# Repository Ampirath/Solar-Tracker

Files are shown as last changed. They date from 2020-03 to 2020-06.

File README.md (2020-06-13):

# Solar-Tracker

ΕΠΑΛ ΚΙΣΑΜΟΥ-ΓΕΛ ΚΙΣΑΜΟΥ

Η ηλιακή ενέργεια αποτελεί ανανεώσιμη πηγή ενέργειας με πρόσφορη μέθοδο χρησιμοποίησή της τα φωτοβολταϊκά πάνελ. Όμως ο ήλιος αποδίδει τα μέγιστα μόνο όταν «πέφτει» κάθετα στο πάνελ, έτσι ψάχνουμε τρόπο να ακολουθεί το πάνελ τις ακτίνες του ήλιου. Ένας τρόπος παρακολούθησης του είναι με φωτοευαίσθητες αντιστάσεις οι οποίες παρακολουθούνται από τον μικροελεγκτή arduino και με servo ο μικροελεγκτής προσαρμόζει το πάνελ ώστε οι ακτίνες να πέφτουν κάθετα. 

Υλικά :

1.arduino uno 
2. 4 ldr 
3. 2 servo (link: https://grobotronics.com/servo-small-5kg.cm-metal-gears-with-analog-feedback-feetech-fs9225m.html                                       https://grobotronics.com/analog-feedback-micro-servo-plastic-gear.html ) 
4.wires 
5.breadboard (link: https://grobotronics.com/adafruit-perma-proto-quarter-sized-breadboard-pcb-single.html ) 
6.Πλαστικά γρανάζια απο 3D εκτυπωτή του εκφέ χανίων (ΤΑ STL ΑΡΧΕΙΑ ΠΕΡΙΛΑΜΒΑΝΟΝΤΑΙ ΩΣ STL-files )

ΤΕΛΙΚΗ ΠΕΡΙΓΡΑΦΗ ΠΡΟΒΛΗΜΑΤΟΣ

Η εποχή μας απαιτεί μεγάλα ενεργειακά αποθέματα , έτσι ένα αποδοτικό φωτοβολταικό πάνελ που ακολουθεί τον ήλιο μας δείχνει τον δρόμο στους κατασκευαστές φωτοβ.συστημάτων. Πόσο μάλλον όταν το πρότζεκτ μας καταγράφει online τις γωνίες που δημιουργεί ο ήλιος στην περιοχή όπου χρησιμοποιείται και έτσι δείχνει ανα ημέρα και ώρα την κατάλληλη γωνία που πρέπει να έχει το φ. πάνελ για μέγιστη απόδοση. 
Το μοίρασμα της γνώσης προτεραιότητα μας! Μια επιστημονική εργασία αυτού του είδους εκπαιδεύει τους μελλοντικούς μας επιστήμονες στο διαθεματικό πλαίσιο STEM-ΘΕΤΙΚΕΣ ΕΠΙΣΤΗΜΕΣ-ΡΟΜΠΟΤΙΚΗ - ΑΚΟΛΟΥΘΩΝΤΑΣ ΤΟ ΜΟΝΟΠΑΤΙ ΤΟΥ ΗΛΙΟΥ.
Σε συνέχεια της προηγούμενης απάντησης η ιδέα μας ήταν να κατασκευάσουμε ένα ηλιακό ανιχνευτή της πορείας του ήλιου που θα προσαρμόζει το φωτοβολταικό πάνελ μας κάθετα στις ακτίνες του ήλιου για να έχει την μέγιστη απόδοση και ταυτόχρονα θα καταγράφει τις γωνίες αυτές.
Χρησιμοποιήσαμε 4 ldr φωτοαντιστάσεις -οι αισθητήρες φωτός που ανάλογα με το φως που λαμβάνουν θα δίνουν εντολή να στραφεί το πάνελ μας στη σωστή θέση- 2 σερβομηχανισμούς για να εκτελούν τις παραπάνω εντολές και θα αποτελούν συνάμα αισθητήρες κλίσης για την καταγραφή αυτών των γωνιών. Φυσικά και ένα arduino που είναι ο εγκέφαλος της κατασκευής μας. Τα 3D εκτυπωμένα εξαρτήματα δίνουν σταθερότητα και αποδοτικότητα στην κατασκευή μας. 
Η ομάδα μας αποτελείται απο 3 μαθητές του ΓΕΛ Κισάμου β λυκείου με θαυμαστή όρεξη για μάθηση: 
ΑΘΗΝΑ ΑΘΑΝΑΣΑΚΗ, ΣΤΕΛΑ ΑΜΠΟΥΧΑΝΗ, ΣΠΥΡΟΣ ΕΙΡΗΝΑΚΗΣ 
Τα κορίτσια είναι οι προγραμματίστριες του arduino και ο Σπύρος το πρακτικό μυαλό. (Βέβαια οι απαιτήσεις του έργου ήταν να αναμιχθούν όλοι σε όλα τα στάδια της κατασκευής). Ο Σπύρος βοήθησε και στο 3D σχεδιασμό εξαρτημάτων. 

ΒΙΒΛΙΟΓΡΑΦΙΚΕΣ ΑΝΑΦΟΡΕΣ

1)https://en.wikipedia.org/wiki/Sun_path 
2)https://en.wikipedia.org/wiki/Position_of_the_Sun 
3)https://www.youtube.com/watch?v=lJVEubm9Ja8 
4)https://www.instructables.com/id/Arduino-Solar-Tracker/

LINK ΠΟΥ ΒΟΗΘΗΣΕ ΣΤΗΝ ΒΑΘΜΟΝΟΜΗΣΗ-CALIBRATION SERVO : https://dronebotworkshop.com/analog-feedback-servo-motor/

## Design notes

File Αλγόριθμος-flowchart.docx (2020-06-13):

ΕΑΝ ΠΑΝΩ>ΚΑΤΩ

VERT.SERVO ΠΑΝΩ-ΒΟΡΕΙΑ

ΑΛΛΙΩΣ ΕΑΝ ΚΑΤΩ >ΠΑΝΩ

VERT.SERVO ΚΑΤΩ-ΝΟΤΙΑ

VERT,SERVO ΚΑΤΩ

ΕΑΝ ΟΙ ΔΕΞΙΟΙ-ΑΡΙΣΤΕΡΟΙ ΑΙΣΘΗΤΗΡΕΣ ΕΧΟΥΝ ΜΕΓΑΛΥΤΕΡΗ ΔΙΑΦΟΡΑ ΑΠΟ ΤΗΝ ΕΠΙΤΡΕΠΟΜΕΝΗ

↓

ΚΑΤΕΓΡΑΨΕ ΓΩΝΙΕΣ

1) γωνία ύψους-altitude και

2) azimuth-ΑΖΙΜΟΥΘΙΟ

VOID SETUP (ΤΡΕΧΕΙ ΜΙΑ ΦΟΡΑ)

ΑΡΧΙΚΟΠΟΙΗΣΗ ΣΕΙΡΙΑΚΗΣ ΕΠΙΚΟΙΝΩΝΙΑΣ

horizontal SERVO.attach PIN

vertical SERVO.attach PIN

ΧΡΗΣΙΜΟΠΟΙΗΣΗ SERVO ΒΙΒΛΙΟΘΗΚΗΣ

ΚΑΘΟΡΙΣΜΟΣ PIN ΓΙΑ ΚΑΤΩ-HORIZONTAL SERVO ΚΑΙ FEEDBACK ANALOG PIN ΚΑΙ ΟΡΙΑ-LIMITS SERVO

ΚΑΘΟΡΙΣΜΟΣ PIN ΓΙΑ ΠΑΝΩ-VERTICAL SERVO ΚΑΙ FEEDBACK ANALOG PIN ΚΑΙ ΟΡΙΑ-LIMOTS SERVO

ΚΑΘΟΡΙΣΜΟΣ ANALOG PIN ΓΙΑ LDR SENSOR

ΔΙΑΒΑΣΜΑ ΑΠΟ LDR SENSORS ΚΑΙ ΥΠΟΛΟΓΙΣΜΟΣ ΜΕΣΩΝ ΤΙΜΩΝ LDR ,ΠΑΝΩ-ΚΑΤΩ ΚΑΙ ΔΕΞΙΑ ΑΡΙΣΤΕΡΑ

ΕΑΝ ΟΙ ΠΑΝΩ- ΚΑΤΩ ΑΙΣΘΗΤΗΡΕΣ ΕΧΟΥΝ ΜΕΓΑΛΥΤΕΡΗ ΔΙΑΦΟΡΑ ΑΠΟ ΤΗΝ ΕΠΙΤΡΕΠΟΜΕΝΗ

↓

ΚΑΤΕΓΡΑΨΕ ΓΩΝΙΕΣ

1) γωνία ύψους-altitude και

2) azimuth-ΑΖΙΜΟΥΘΙΟ

ΕΑΝ ΔΕΞΙΟΙ>ΑΡΙΣΤΕΡΟΙ

HORIZ.SERVO ΔΕΞΙΑ-ΑΝΑΤΟΛΙΚΑ

ΑΛΛΙΩΣ ΕΑΝ ΑΡΙΣΤΕΡΟΙ>ΔΕΞΙΟΙ

HORIZ.SERVO ΑΡΙΣΤΕΡΑ-ΔΥΤΙΚΑ

VOID LOOP (ΕΠΑΝΑΛΑΜΒΑΝΟΜΕΜΗ ΛΟΥΠΑ)

MAP-ΧΑΡΤΗΣ ΠΟΥ ΠΡΟΕΚΥΨΕ ΜΕΤΑ ΑΠΟ CALIBRATION Α)ΓΙΑ ΑΖΙΜΟΥΘΙΟ-AZIMUTH

,, Β)ΓΙΑ ΥΨΟΣ-ALTITUDE

ΑΡΧΗ ΠΡΟΓΡΑΜΜΑΤΟΣ

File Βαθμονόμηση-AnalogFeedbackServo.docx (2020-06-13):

ΔΙΑΔΙΚΑΣΙΑ ΒΑΘΜΟΝΟΜΗΣΗΣ ANALOG FEEDBACK SERVO

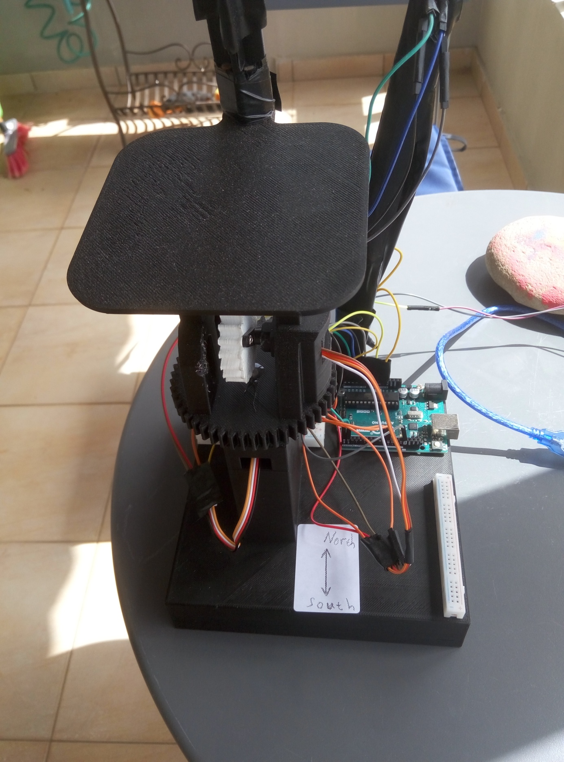
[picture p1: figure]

Κατά την τοποθέτηση προσέχουμε το κάτω servo να χει περιθώριο κινήσεων σε σχέση με τον νότο-south(βλέπε εικόνα) δεξιά –ανατολή 90⁰ ,αριστερά- δύση 90⁰ και με το πρόγραμμα recalibrationhorizontalservo.ino έχοντας σημαδέψει τις 90⁰ δεξιά αριστερά , βάζοντας σε //comment τις 35 και 36 γραμμές βρίσκουμε την αληθή αντιστοίχηση μεταξύ feedbackValue και γωνίας. Έπειτα προσθέτουμε τις γραμμές *

## feedbackValue = analogRead(feedbackPin);

## angle=map(feedbackValueh,84,424,-90,90);

## Βάζοντας στην θέση 84,424 τις τιμές που θα βρείτε εσείς και αντιστοιχούν στις γωνίες -90 ,90.

## *Τις γραμμές αυτές του κώδικα τις τοποθετείτε στην ίδια θέση του mainprogram.

## Αντίστοιχα εργαζόμαστε για το πάνω –vertical servo .Το πρόγραμμα CALIBRATIONANALOGSERVOvertical.ino ουσιαστικά είναι ίδιο με το recalibrationhorizontalservo.ino.

## Στο παρακάτω link αντλήσαμε πληροφορίες για την βαθμονόμηση αλλά και για αυτά τα analogfeedback servo:

## https://dronebotworkshop.com/analog-feedback-servo-motor/

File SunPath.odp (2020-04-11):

## Βρίσκοντας το μονοπάτι του ήλιου

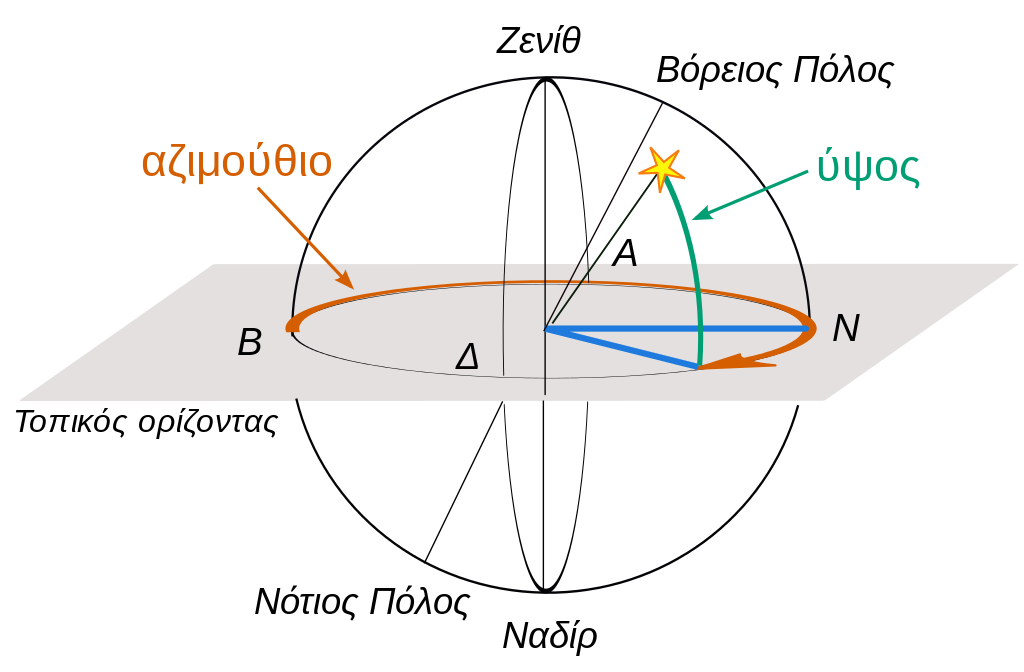
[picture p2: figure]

## Η διαδρομή του ήλιου

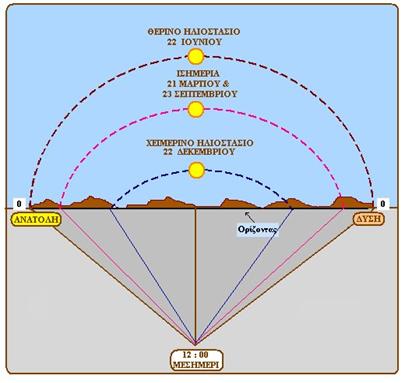
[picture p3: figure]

## Ύψος ήλιου (κλίση επιφάνειας) (altitude)

  Το ύψος του ήλιου αναφέρεται στη γωνία που σχηματίζει ο ήλιος με τον ορίζοντα της Γης. Αφού ειναι γωνία, μετριέται σε μήρες.
  Η κλίση είναι 0° στην ανατολή του ηλίου και στην δύση του και μπορεί να φτάσει τις 90° (ζενίθ) το μεσημέρι, σε μέρη κοντά στον ισημερινό.
  Λόγω της κλίσης του άξονα περιστροφής της γης η θέση του ήλιου στον ουρανό του ισημερινού το μεσημέρι θα αποκλίνει στη διάρκεια του έτους κατά +/- 23.5 μοίρες από το απολύτως κάθετο (ζενίθ).

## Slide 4

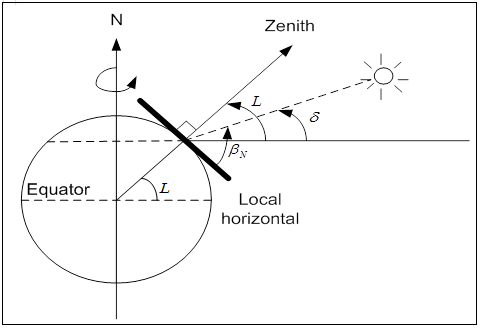
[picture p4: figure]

## Γωνία αζιμούθιου (azimuth)

  Είναι η γωνία προς την οποία ειναι στραμμένη μια επιφάνεια.
  Συνήθως μετριέται απο το Βορρά (0° / 360°) προς την Ανατολή.

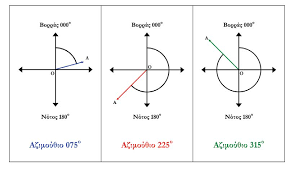
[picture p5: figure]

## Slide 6

  Ή μπορούμε ανάλογα το ημισφαίριο να το ορίσουμε διαφορετικά.
  Για τοποθεσίες του βόρειου ηµισφαιρίου µηδενική τιµή του αζιμούθιου γ αντιστοιχεί σε νότια κατεύθυνση, θετικές τιµές του αναφέρονται σε δυτικούς προσανατολισµούς, και αρνητικές τιµές του γ σε ανατολικούς προσανατολισµούς.

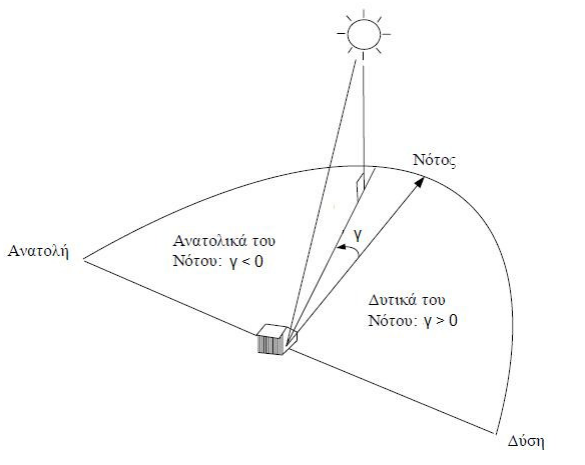
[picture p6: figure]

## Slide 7

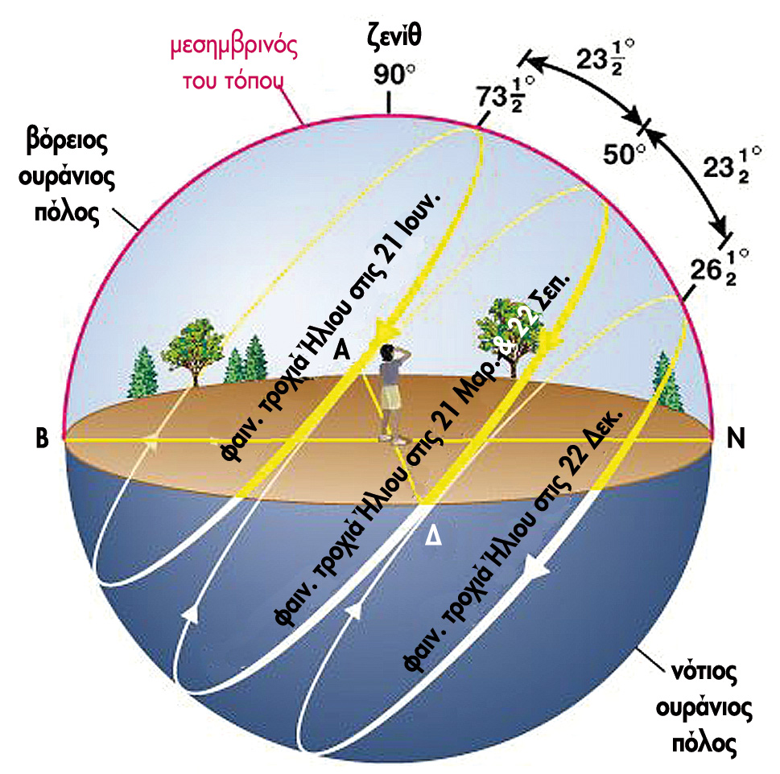
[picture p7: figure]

  Αθηνά Μαρία Αθανασάκη – ΓΕΛ Κισάμου

## ΠΗΓΕΣ

- Motions of the Sun simulator (https://ccnmtl.github.io/astro-simulations/sun-motion-simulator/)
- Sun Path (wikipedia) (https://en.wikipedia.org/wiki/Sun_path)
- Position of the Sun (wikipedia) (https://en.wikipedia.org/wiki/Position_of_the_Sun)
- Solar altitude (https://sciencing.com/solar-altitude-23364.html)
- Solar Zenith Angle (wikipedia) (https://en.wikipedia.org/wiki/Solar_zenith_angle)
- Solar Azimuth (wikipedia) (https://en.wikipedia.org/wiki/Solar_azimuth_angle)
- Διάγραμμα μονοπατιού (https://www.sunearthtools.com/dp/tools/pos_sun.php)
- Μονοπάτι του Ήλιου στην Αθήνα (https://acomelectronics.com/forum/viewtopic.php?t=20)
- Ηλιακή Ακτινοβολία - Γεωμετρία

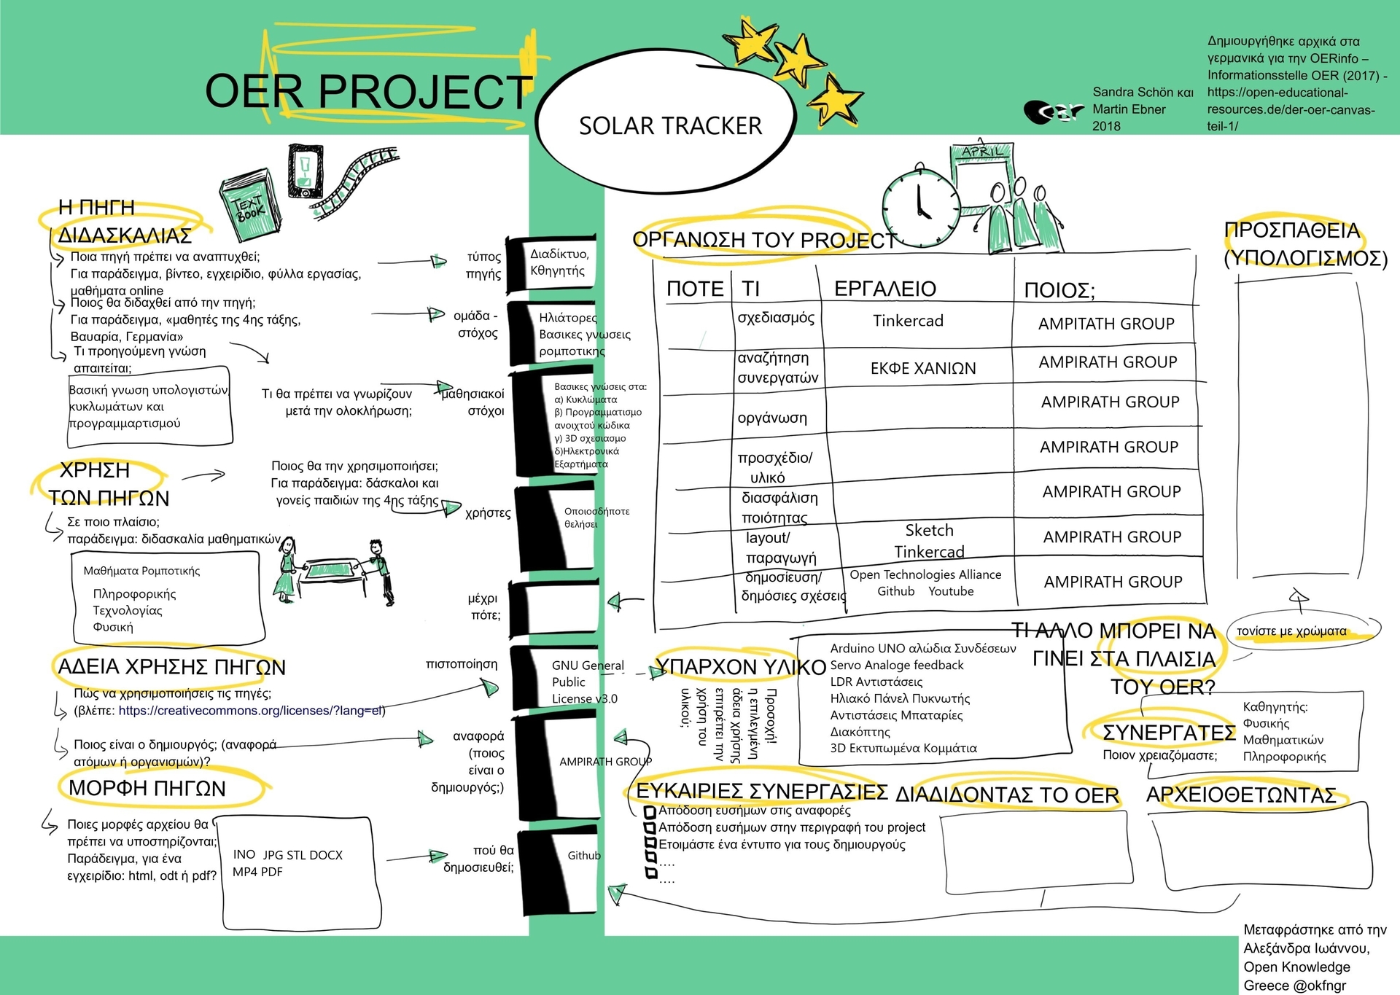
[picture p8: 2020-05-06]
OER CANVAS SOLAR TRACKER.jpg

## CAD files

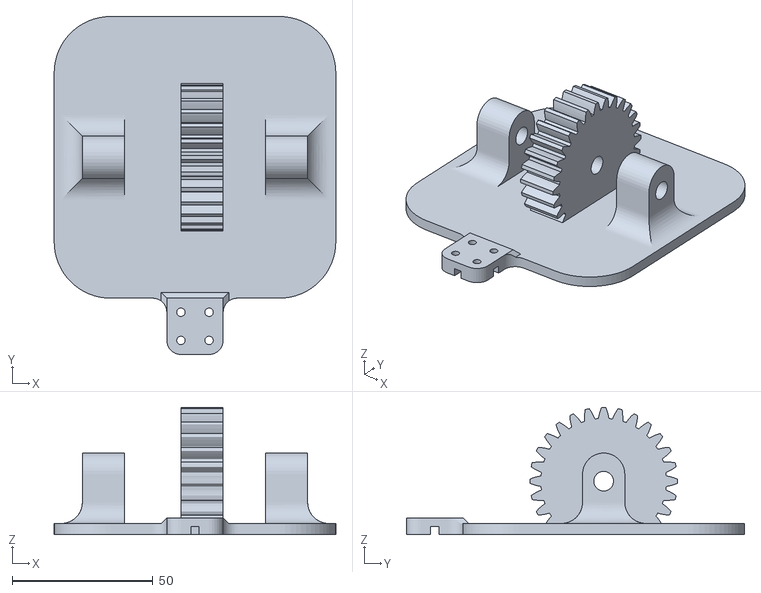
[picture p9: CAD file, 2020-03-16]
stl-files/Panel_Bracket2.stl
100.0 x 120.0 x 45.2

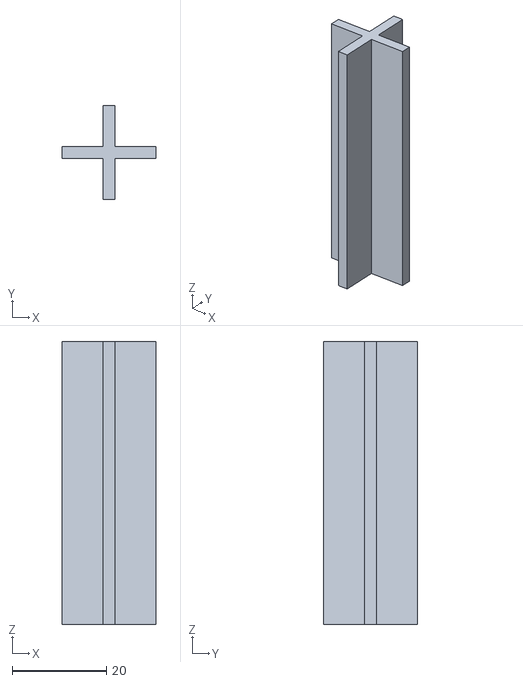
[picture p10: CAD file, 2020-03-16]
stl-files/LDR DIVIDER HIGH.stl
20.0 x 20.0 x 60.0

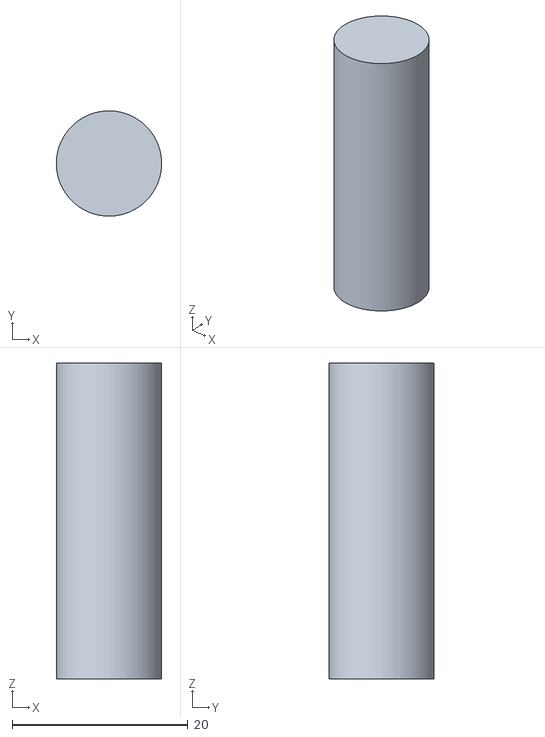
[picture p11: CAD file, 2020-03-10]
stl-files/Base_Gear_Shaft.stl
12.0 x 12.0 x 36.0

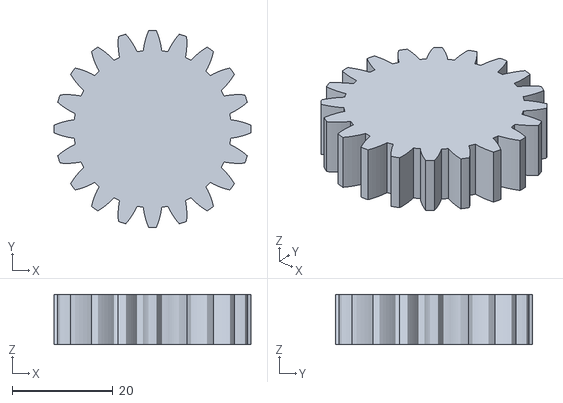
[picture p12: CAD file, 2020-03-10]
stl-files/Vertical_Servo_Gear.stl
39.2 x 39.2 x 10.0

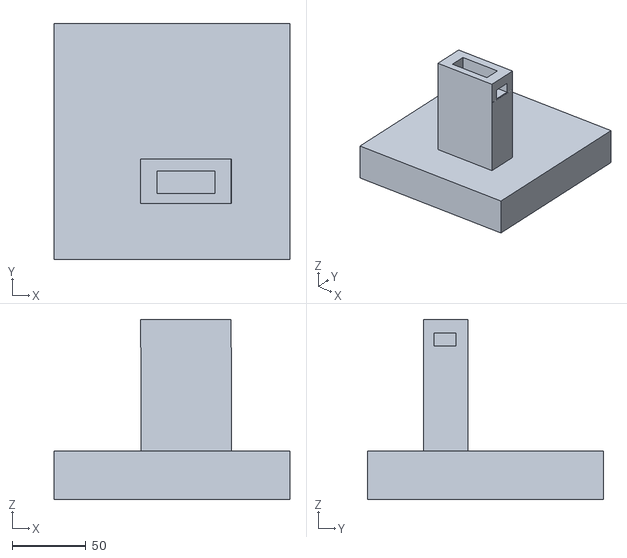
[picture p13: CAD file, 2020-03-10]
stl-files/base.stl
160.0 x 160.0 x 122.1

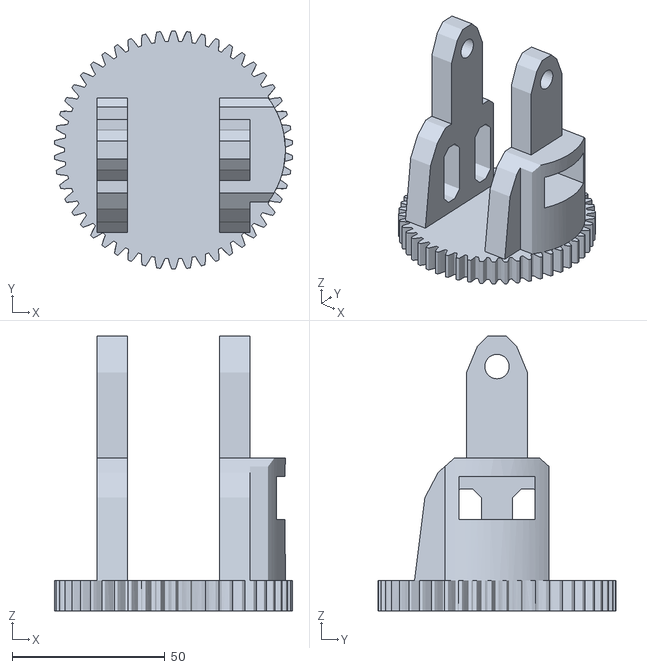
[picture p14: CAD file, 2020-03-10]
stl-files/panel-mount.stl
77.9 x 78.0 x 90.0

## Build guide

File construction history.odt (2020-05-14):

Solar Path Finder

Ιστορικό κατασκεύης

Ξεκινήσαμε κάνοντας εβδομαδιαία μαθήματα ρομποτικής με τον Κ. Κουράκη. Άφου μάθαμε τα βασικά γύρω απο τα κυκλώματα, τον προγραμματισμό και το arduino, προχωρήσαμε σε διάφορες μικρές εργασίες-project για να γίνουμε πιο οικείοι με το arduino.

Μετά από ψάξιμο στο ίντερνετ καταλήξαμε ότι η κατασκευή με την οποία θέλαμε να ασχοληθούμε ήταν ένα solar finder, μιάς και είναι μια συσκευή μέσα στην επικαιρότητα των ημερών αλλά και προσφέρει πολλά περιθώρια για εξέλιξη και πειραματισμό.

Από τις παρακάτω πηγές, πήραμε την αρχική ιδέα για το πως θα έπρεπε να μοιάζει η συσκευή, τη λογική της λειτουργίας της και τον τρόπο προγραμματισμού της.

https://www.instructables.com/id/Arduino-Solar-Tracker/

και τα 3d stl αρχεία από:

https://www.thingiverse.com/thing:53321

(Τα οποία τελικά τα ανασχεδιάσαμε με το online tinkercad)

Έτσι με βάση αυτές, φτιάξαμε μια πρόχειρη κατασκευή χρησιμοποιώντας υλικά απο παιδικά παιχνίδια για να διαπιστώσουμε αν το solar tracker, όντως δούλευε όπως έπρεπε.

Αφού η δοκιμή ολοκληρώθηκε με μερική αποτυχία ,αναγκαστήκαμε να κατανοήσουμε πληρώς το hardware-software και με πολλές διορθώσεις και αλλαγές η 5η δοκιμή μας κατέληξε σε επιτυχία. Ζητήσαμε απο το ΕΚΦΕ Χανίων να μας εκτυπώσει τα 3D κομμάτια που χρειαζόμασταν.

Ξεκινήσαμε γράφοντας ένα απλό πρόγραμμα, ώστε το φωτοβολταϊκό να στρέφεται προς την κατεύθυνση με το περισσότερο φως. Αποφασίσαμε όμως ότι μια ακόμα χρήσιμη εφαρμογή του solar path finder θα ήταν η αποστολή δεδομένων της θέσης του. Με αυτό τον τρόπο μπορούμε να έχουμε καταγραφή των γωνιών που διαγράφει και έτσι, όταν τοποθετείται σε εξωτερικό χώρο, παίρνουμε ξεκάθαρη εικόνα του μονοπατιού του ήλιου σε εκείνη την περιοχή.

Για να το κάνουμε αυτό έπρεπε πρώτα να κατανοήσουμε τον τρόπο με τον οποίο κινείται ο ήλιος και το πως γίνονται αυτές οι μετρήσεις στην πραγματικότητα, ώστε να βρούμε ενα τρόπο για να το κάνουμε μέσω της κατασκευής μας.

Αρχικά προσπαθήσαμε να το κάνουμε με την βοήθεια ενός αισθητήρα επιτάχυνσης-γυροσκοπίου-μαγνητόμετρου, όμως αποδείχθηκε ότι δεν ήταν εύκολο και το ποσοστό σφάλματος ήταν μεγάλο. Με επίπονη βαθμονόμηση-calibration τελικά δούλεψε ικανοποιητικά αλλά ο καθηγητής ,μας προέτρεψε να ασχοληθούμε-εξελίξουμε έναν πιο απλό τρόπο εύρεσης των γωνιών του Ήλιου. Οπότε αποφασίσαμε να αντικαταστήσουμε τα δύο απλά servo με αυτά που στέλνουν πίσω τη θέση στην οποία βρίσκεται το servo σωστά. ( analogfeedback servo).

Μη θέλοντας να διαλύσουμε την πρώτη μας κατασκευή, αποφασίσαμε να ξαναφτιάξουμε ολόκληρο το solar path finder από το μηδέν, κάνοντας ταυτόχρονα και κάποιες διορθώσεις στην δομή του, για να γίνεται πιό σωστή και ομαλή η λειτουργεία του.

Τελικά επανασχεδιάσαμε τα 3d εξαρτήματα 1)για να μπουν τα καινούργια-διαφορετικών διαστάσεων servo στην θέση των παλιών

2)για να μπορεί η κατασκευή να δουλέψει σε εξωτερικό χώρο και να μετράει σωστά τις γωνίες altitude,azimuth του Ήλιου (η πηγή μας και ο αντίστοιχος δημιουργός της https://www.thingiverse.com/thing:53321 - προνόησε μόνο μια κατασκευή επίδειξης -απλά solar tracker- για εσωτερικό χώρο).

Για να σιγουρευτούμε ότι οι τιμές που παίρναμε απο το servo ήταν σωστές, κάναμε κάποιες δοκιμές , βαθμονόμηση των servo(calibration).

Καταλήξαμε στην δημιουργία χαρτών -map, ώστε να γίνει αναλογία των τιμών που έδινε με τις πραγματικές.

Έπειτα, ξαναγράψαμε το πρόγραμμα του solar path finder κάνοντας τις απαραίτητες αλλαγές και το δοκιμάσαμε αρκετές φορές, ώστε να λύσουμε τυχόν σφάλματα που παρουσίαζε στην λειτουργία του.

Με το δικό μας λογισμικό μπορεί να γινεί live αναπαραγωγή των δεδομένων που συλλέγει το solar path finder και έτσι οποιοσδήποτε και απο οπουδήποτε να έχει πρόσβαση σε αυτές τις πληροφοριές τις οποίες μπορεί να χρησιμοποιήσει για τις δικές του εργασίες.

ΓΕΛ – ΕΠΑΛ ΚΙΣΑΜΟΥ(ΣΥΝΕΡΓΑΣΙΑ)

Οι μαθητές :

ΑΘΗΝΑ ΑΘΑΝΑΣΑΚΗ

ΣΠΥΡΙΔΩΝ ΕΙΡΗΝΑΚΗΣ

ΣΤΕΛΛΑ ΑΜΠΟΥΧΑΝΗ

Ο επιβλέπων καθηγητής:

ΚΟΥΡΑΚΗΣ ΝΕΚΤΑΡΙΟΣ

ΣΥΝΤΑΚΤΗΣ:ΑΘΗΝΑ ΑΘΑΝΑΣΑΚΗ

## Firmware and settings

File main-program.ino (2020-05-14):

#include <Servo.h> 

int feedbackPinv = A5;
int feedbackValuev;
int feedbackPinh = A4;
int feedbackValueh;

int altitude;
int angle;  


Servo horizontal; 
int servoh = 65;  
int servohLimitHigh = 130;
int servohLimitLow = 0;
int servoPin = 9;


Servo vertical;   
int servov = 114;   
int servovLimitHigh = 135;
int servovLimitLow = 5;
int servoPinv = 10;


int ldrlt =A0;   
int ldrrt =A1;
int ldrld =A2; 
int ldrrd =A3; 

void setup()
{
  Serial.begin(9600);
// servo connections
// name.attacht(pin);
  horizontal.attach(9); 
  vertical.attach(10);
  horizontal.write(65);
  vertical.write(114);
  delay(3000);

  Serial.print( ' altitude = ,');
  Serial.println('azimuth = ');
  
}

void loop() 
{
   feedbackValueh = analogRead(feedbackPinh);
   angle=map(feedbackValueh,84,424,-90,90);
   feedbackValuev = analogRead(feedbackPinv);
   altitude=map(feedbackValuev,127,492,8,120);
   
  int lt = analogRead(ldrlt); 
  int rt = analogRead(ldrrt); 
  int ld = analogRead(ldrld); 
  int rd = analogRead(ldrrd);
  
  
  int dtime = 10;
  int tol = 50;
  
  int avt = (lt + rt) / 2; 
  int avd = (ld + rd) / 2; 
  int avl = (lt + ld) / 2; 
  int avr = (rt + rd) / 2;
  
  int dvert = avt - avd; 
  int dhoriz = avl - avr;
  
  
    
  if (-1*tol > dvert || dvert > tol) 
  {
  if (avt > avd)
  {
    servov = ++servov;
     if (servov > servovLimitHigh) 
     { 
      servov = servovLimitHigh;
     }
  }
  else if (avt < avd)
  {
    servov= --servov;
    if (servov < servovLimitLow)
  {
    servov = servovLimitLow;
  }
  }
  vertical.write(servov);
  Serial.print(altitude);
  Serial.print(",");
  Serial.print(angle);
  delay(35);
  }
  
  if (-1*tol > dhoriz || dhoriz > tol) 
  {
  if (avr > avl)
  {
    servoh = ++servoh;
    if (servoh > servohLimitHigh)
    {
    servoh = servohLimitHigh;
    }
  }
  else if (avr < avl)
  {
    servoh = --servoh;
     if (servoh < servohLimitLow)
     {
     servoh = servohLimitLow;
     }
  }
  else if (avl = avr)
  {
    
  }
  horizontal.write(servoh);
  Serial.print(altitude);
  Serial.print(",");
  Serial.print(angle);
  
  }
   delay(dtime);

}

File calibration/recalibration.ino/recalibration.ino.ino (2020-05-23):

#include <Servo.h>
 
// Control and feedback pins
int servoPin = 9;
int feedbackPin = A0;
int angle; 
// Value from feedback signal
int feedbackValue;
 
// Create a servo object
Servo myservo;
 
void setup()
{
  // Setup Serial Monitor
  Serial.begin(9600);
  
  // Attach myservo object to control pin
  myservo.attach(servoPin);
  
  // Home the servo motor
  myservo.write(0);
  
  
 
    for (int servoPos = 0; servoPos <=180; servoPos = servoPos + 3){
    
    // Position servo motor
    myservo.write(servoPos);
    // Allow time to get there
    delay(2000);
    
    // Read value from feedback signal
    feedbackValue = analogRead(feedbackPin);
    angle=map(feedbackValue,80,400,0,180);
    // Write value to serial monitor
    Serial.print("Position = ");
    Serial.print(angle);
    Serial.print("\t");
    Serial.println(feedbackValue);
  
  }
 
  // Move back to home position
  myservo.write(0);
  
  // Print to serial monitor when done
  Serial.println("Finished!");
 
}  
 
void loop()
{ 
myservo.write(0);
  
  
    for (int servoPos = 0; servoPos <=180; servoPos = servoPos + 3){
    
    // Position servo motor
    myservo.write(servoPos);
    // Allow time to get there
    delay(2000);
    
    // Read value from feedback signal
    feedbackValue = analogRead(feedbackPin);
    angle=map(feedbackValue,80,400,0,180);
 
    // Write value to serial monitor
    Serial.print("Position = ");
    Serial.print(angle);
    Serial.print("\t");
    Serial.println(feedbackValue);
  
  }
 
  // Move back to home position
  myservo.write(0);
  
  // Print to serial monitor when done
  Serial.println("Finished!");
  
}
